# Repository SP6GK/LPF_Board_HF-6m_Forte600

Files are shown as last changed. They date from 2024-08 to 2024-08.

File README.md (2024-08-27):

# LPF_Board_HF-6m_Forte600
Design of a LPF board with 6 filters covering entire HF spectrum and 6 m band. Suitable for 600 W (or more) LDMOS/BJT amplifiers.

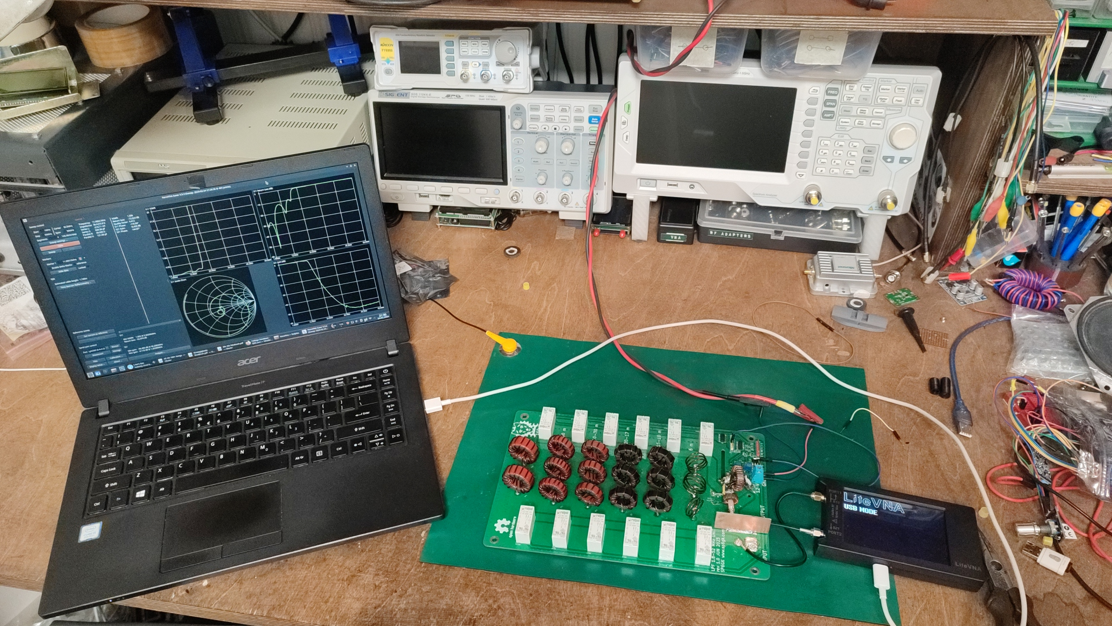
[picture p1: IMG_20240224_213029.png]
LPF_PCB


## Overview

For a detailed theory of operation and a description of the design process, you can read section 2.2.3 of my thesis: [Optimization of HF Amplifier TLT Forte600 Documentation](https://github.com/SP6GK/Forte-600-HF-RF-Amplifier/blob/main/Optimization_HF_amplifier_TLT_Forte600Documentation.pdf).

This low pass filter board was designed for a 600 W amplifier and successfully withstood 600 W of CW power with no issues. It is overrated to handle about 1 kW, however, in such case, the size of some of the toroids should be increased.  
These filters used in the Forte 600 ([Forte 600 project repo](https://github.com/SP6GK/Forte-600-HF-RF-Amplifier)) provide a worst-case harmonic suppression of 54 dBc for the 15 m band. Check the `/Results` directory for S21 and S11 measurements, or refer to sections 4.7 and 4.8 of my thesis for a more in-depth discussion of the results: [Optimization of HF Amplifier TLT Forte600 Documentation](https://github.com/SP6GK/Forte-600-HF-RF-Amplifier/blob/main/Optimization_HF_amplifier_TLT_Forte600Documentation.pdf).  
During assembly use only high quality, high current capable, COG capacitors rated at 1 kV or more.

The board includes a tandem match coupler, allowing the forward and reflected power at the output to be measured. The desired LPF is selected either by applying a low level 5 V signal to connector J4, which requires 7 wires, or by driving a shift register (U2) directly from a microcontroller (3.3 V to 5 V) using only 3 wires.  
The code for band changing and shift register driving is available in my repository for the LDMOS amplifier controller: [Link](https://github.com/SP6GK/RF_Power_Amplifier_Controller_V1).  
To find out more about the Forte 600 project, you can visit my website: [www.sp6gk.com](https://www.sp6gk.com/).

## Directory Structure

- **/bom**  
  Contains an interactive HTML BOM for assembly and the `BOM_LC.ods` spreadsheet, which indicates the number of turns and suggested values for capacitors, ensuring that the combined capacitance value is achieved using at least 4 parallel capacitors.

- **/Gerbers**  
  Files for sending the project to your favorite PCB fabricator.

- **/KiCad**  
  Contains the PCB project files.

- **/PDF**  
  Contains 1:1 scale prints of the copper and silk screen layers.

- **/Results**  
  Contains S21 and S11 measurements of the assembled board. Measurements were made using a calibrated LiteVNA 64, and .s2p files were plotted in AWR Designer.

- **Coilformer1y.stl** & **Coilformer2.stl**  
  Temporary coil formers for the 6m band, which you can 3D print and then wind the coil on.

- **LPF.asc**  
  LTspice simulation of the LPF filters.

- **LPF+6m_Schematic.pdf**  
  schematic document.

- **LPF_live.mlx**  
  A MATLAB Live Script for the calculation of LC elements, formulas and values for polynomials were sourced from "Experimental Methods in RF Design" book.

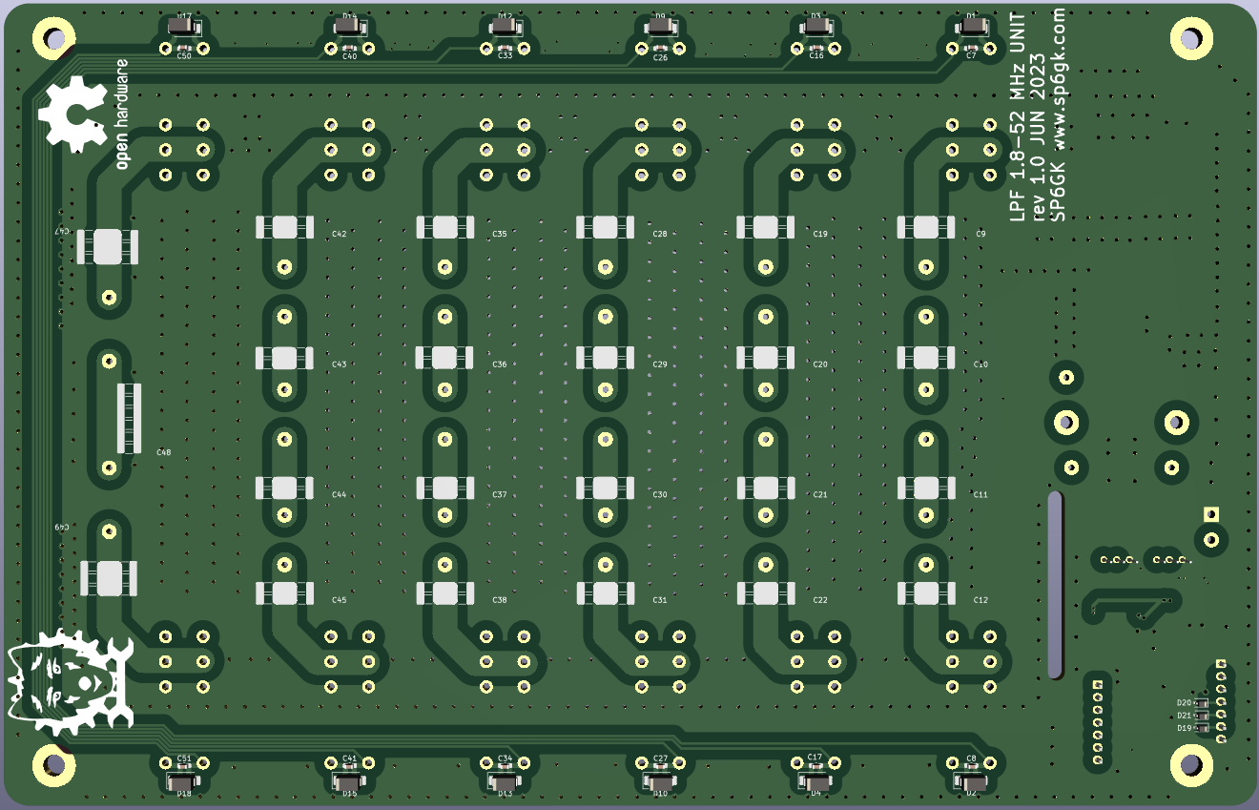
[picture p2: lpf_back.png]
LPF_back


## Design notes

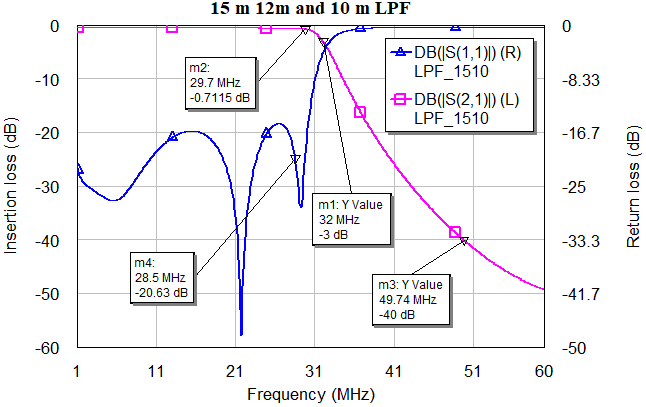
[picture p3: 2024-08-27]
AWR_1510m2.png

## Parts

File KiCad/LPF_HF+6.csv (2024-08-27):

null | Sourced | Placed | References | Value | Footprint | Quantity
1 |  |  | C1, C2, C3, C4, C5, C6, C8, C9, C10, C11, C12, C13, C14, C16, C18, C20, C39, C44, C45, C47, C50 | 100n | 0603 | 21
2 |  |  | C25, C31, C37, C43 | 834p | 4x1206_2 | 4
3 |  |  | C19, C46, C49 | 1u | 0603 | 3
4 |  |  | C26, C32, C38 | C_Small | 6x1206 | 3
5 |  |  | C7, C17 | 10u | 1206 | 2
6 |  |  | C21, C39 | 71p | 4x1206_2 | 2
7 |  |  | C22, C40 | 123p | 4x1206_2 | 2
8 |  |  | C23, C41 | 203p | 4x1206_2 | 2
9 |  |  | C24, C42 | 357p | 4x1206_2 | 2
10 |  |  | C27, C33 | 127p | 4x1206_2 | 2
11 |  |  | C28, C34 | 218p | 4x1206_2 | 2
12 |  |  | C29, C35 | 360p | 4x1206_2 | 2
13 |  |  | C30, C36 | 635p | 4x1206_2 | 2
14 |  |  | C48, C51 | 10n | 0603 | 2
15 |  |  | C15 | 10u | 1206 | 1
16 |  |  | R2, R3, R4, R5, R12, R13 | 100 | 0603 | 6
17 |  |  | R6, R7, R9, R10 | 100 | 2010 | 4
18 |  |  | R8, R11 | 10k | 0603 | 2
19 |  |  | R1 | 10 | 0603 | 1
20 |  |  | L1, L2, L3, L4, L5, L7, L8, L9, L10, L11, L13, L14, L15, L16, L17 | L | T94-Inductor | 15
21 |  |  | L6, L12 | L | T106-Inductor | 2
22 |  |  | L20, L21 | 100u | 0805 | 2
23 |  |  | L18 | FT50-61 30T 1T RG-142 coax | T94-SWR_TRAFO | 1
24 |  |  | L19 | FT82-61 30T 1T-RG213 coax | T94-SWR_TRAFO | 1
25 |  |  | D1, D2, D3, D4, D5, D6, D10, D11, D12, D13, D14, D15 | 1N4007 | D_SMA | 12
26 |  |  | D7, D8, D9, D16, D17, D18, D21, D22 | SD12_SOD323 | D_SOD-323 | 8
27 |  |  | D19, D20 | Schottky | D_SMA | 2
28 |  |  | U1 | AMS1117-5 | SOT-223-3_TabPin2 | 1
29 |  |  | U2 | 74AHC595 | SO-16_3.9x9.9mm_P1.27mm | 1
30 |  |  | U3 | ULN2003 | SO-16_3.9x9.9mm_P1.27mm | 1
31 |  |  | REL1, REL2, REL3, REL4, REL5, REL6, REL7, REL8, REL9, REL10, REL11, REL12 | RM85 | RM85_Relay | 12
32 |  |  | RV1, RV2 | 10k | Potentiometer_Bourns_3266Y_Vertical | 2
33 |  |  | J1, J4 | Conn_01x07 | JST_EH_B7B-EH-A_1x07_P2.50mm_Vertical | 2
34 |  |  | J2 | 12V INPUT | TerminalBlock_bornier-2_P5.08mm | 1
35 |  |  | J3 | RF input | Coax_Mount | 1
36 |  |  | J5 | RF output | Coax_Mount | 1

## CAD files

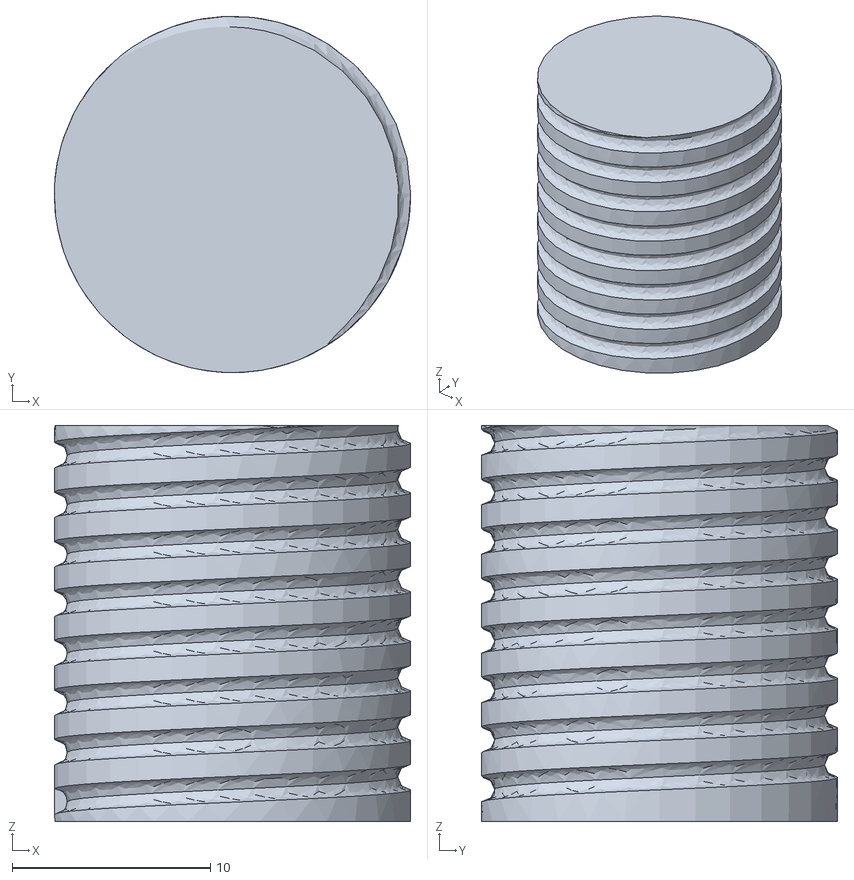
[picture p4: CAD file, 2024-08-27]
Coilformer1y.stl
18.0 x 18.0 x 20.0

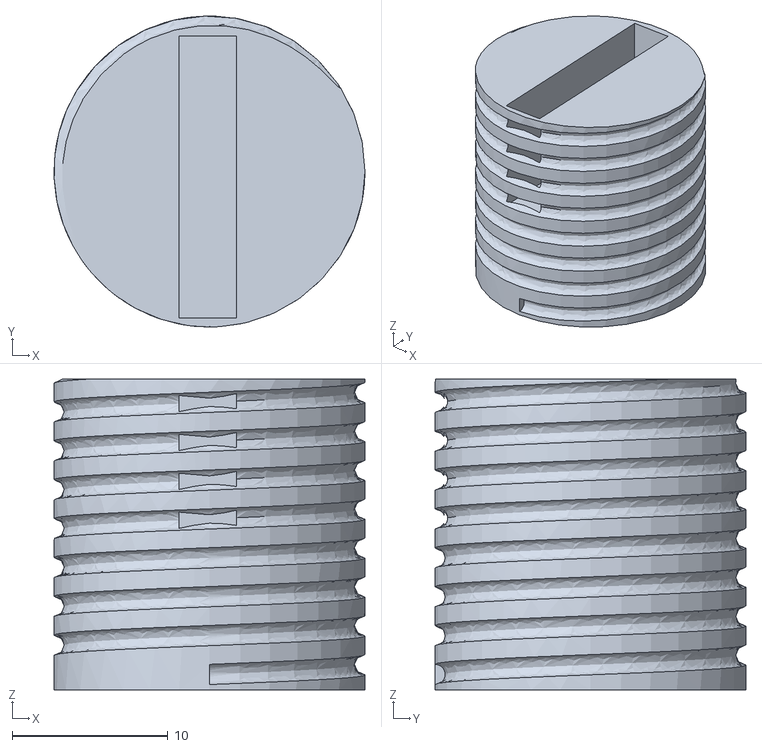
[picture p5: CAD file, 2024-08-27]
Coilformer2.stl
20.0 x 20.0 x 20.0

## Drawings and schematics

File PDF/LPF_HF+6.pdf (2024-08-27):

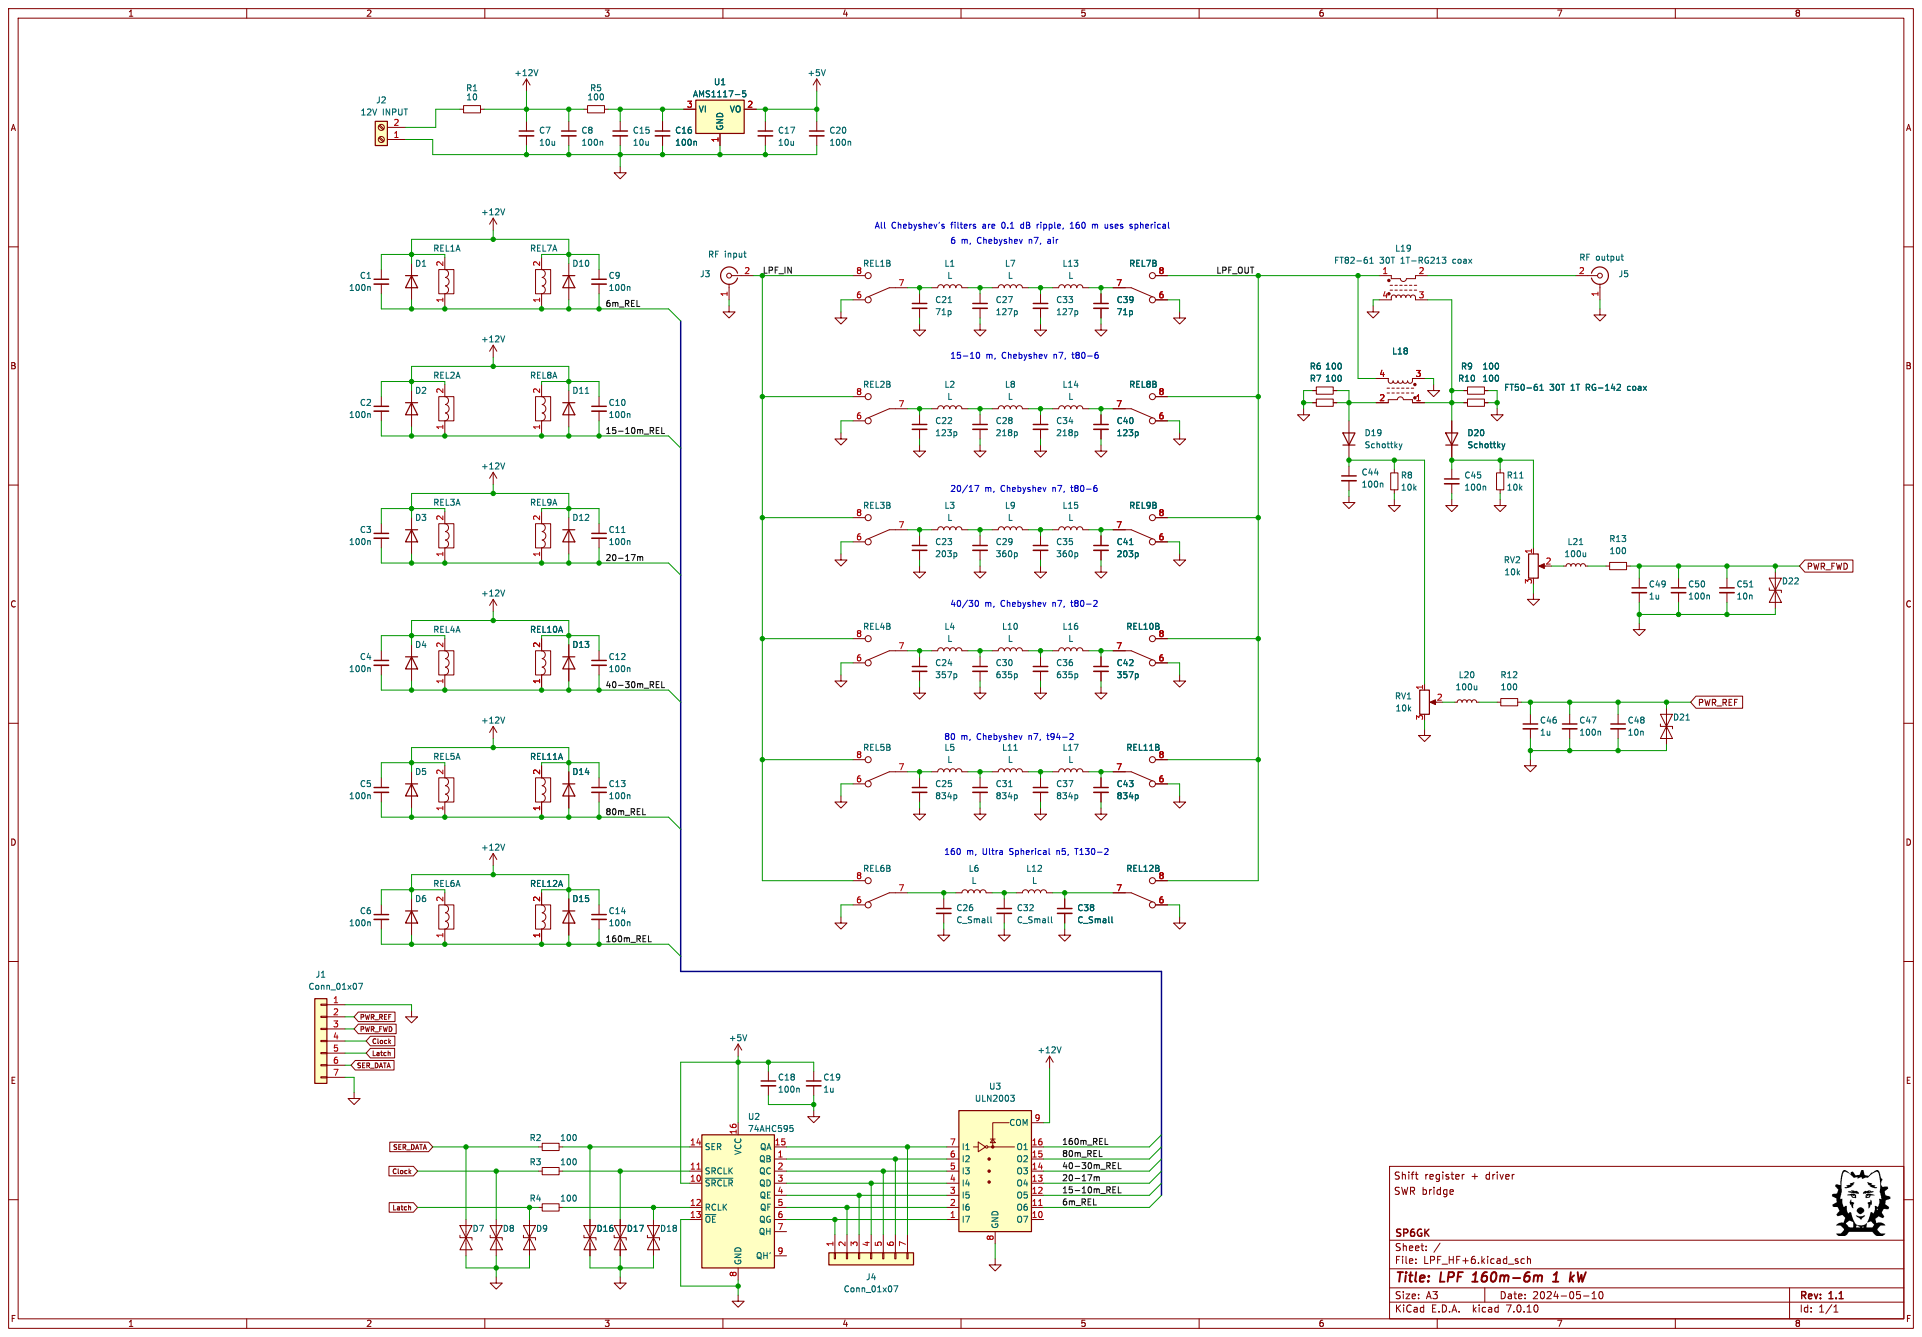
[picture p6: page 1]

1 2 REL12A R2 100 R3 100 D18 QB 1 ~{SRCLR} 10 SRCLK 11 RCLK 12 ~{OE} 13 SER 14 QA 15 VCC 16 QC 2 QD 3 QE 4 QF 5 QG 6 QH 7 GND

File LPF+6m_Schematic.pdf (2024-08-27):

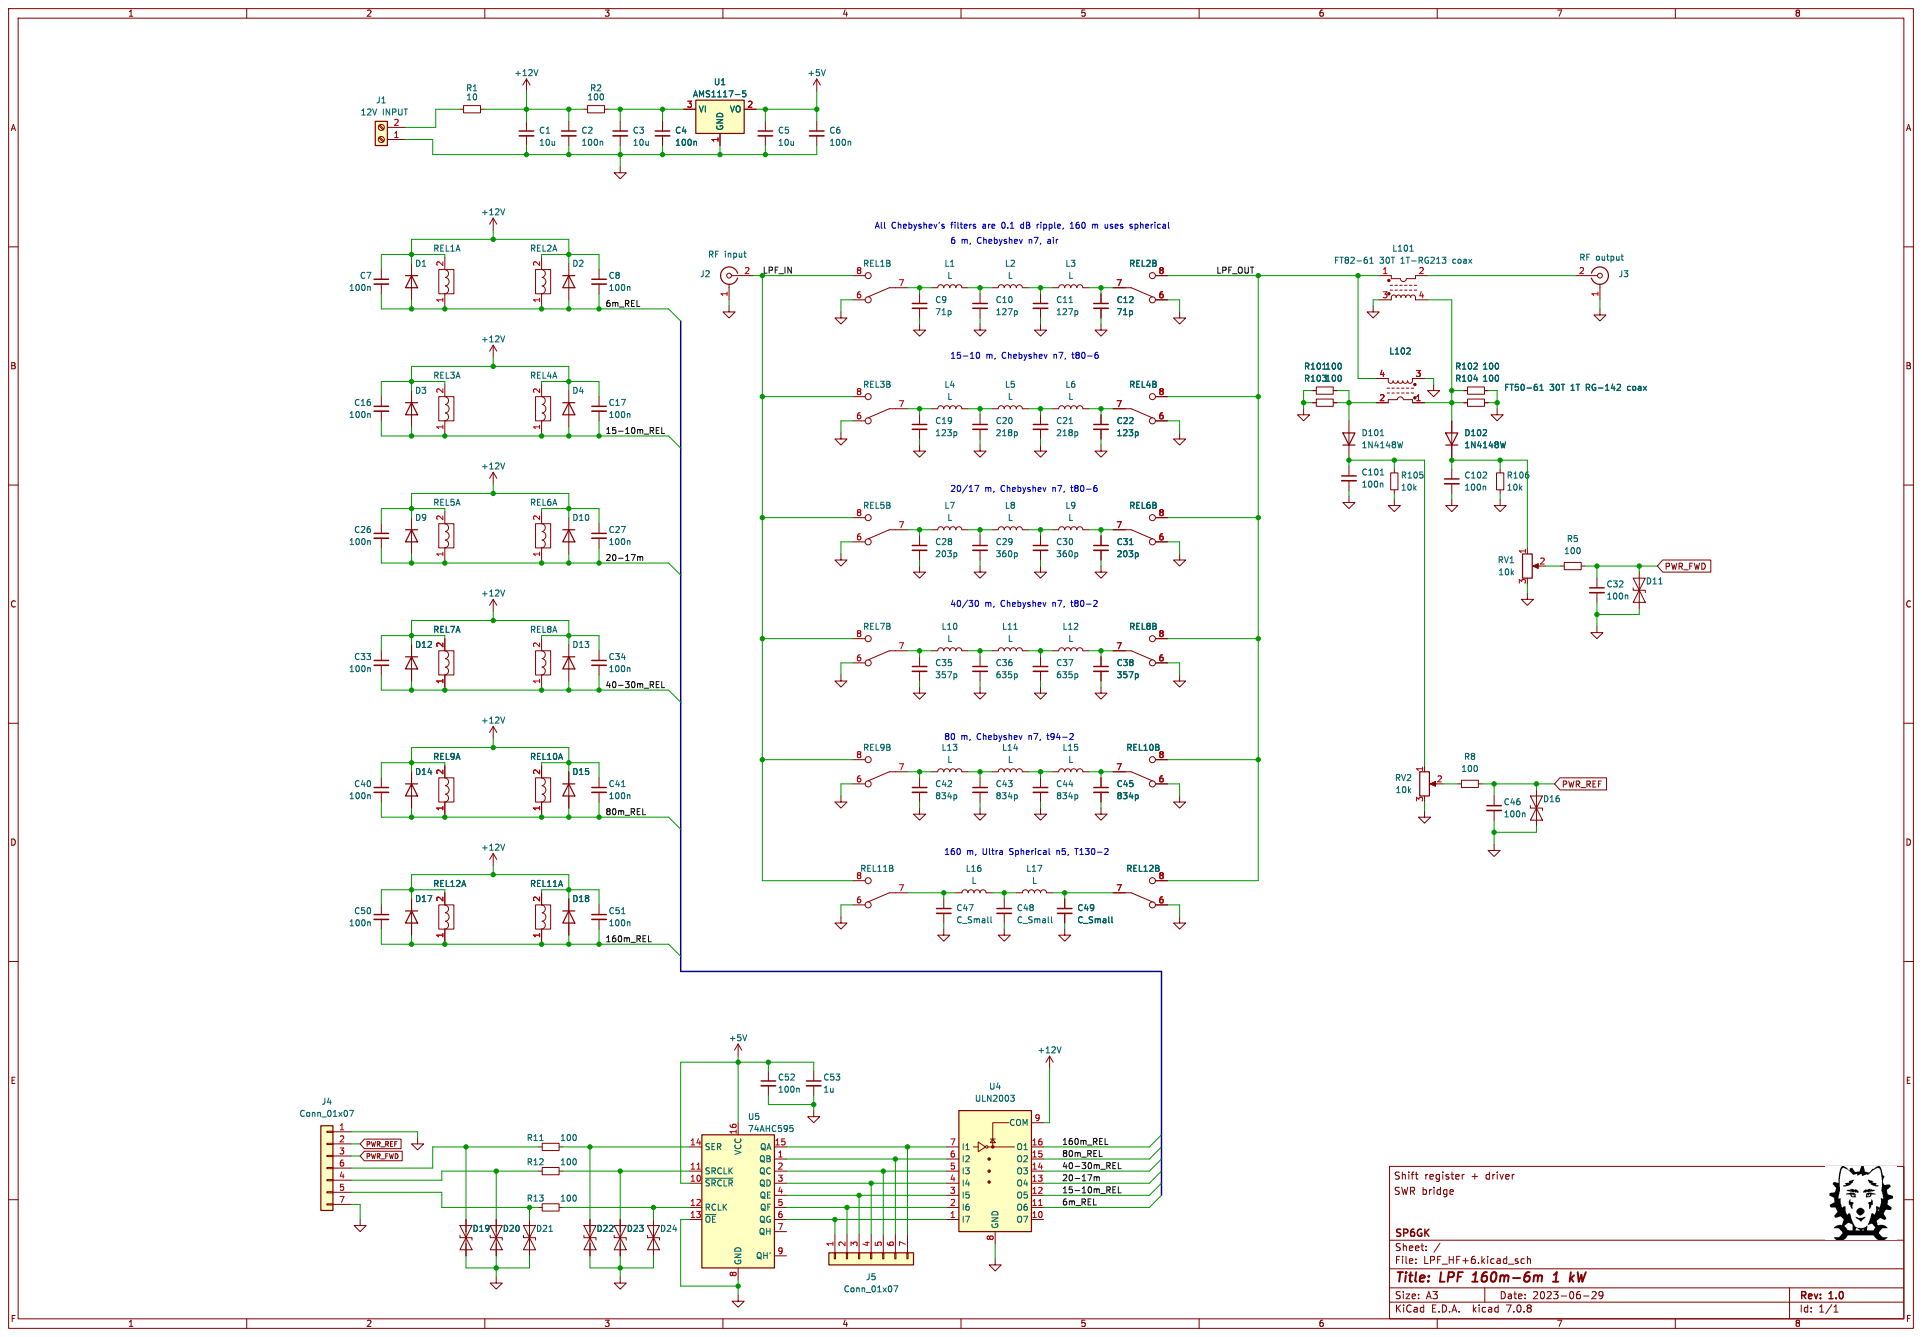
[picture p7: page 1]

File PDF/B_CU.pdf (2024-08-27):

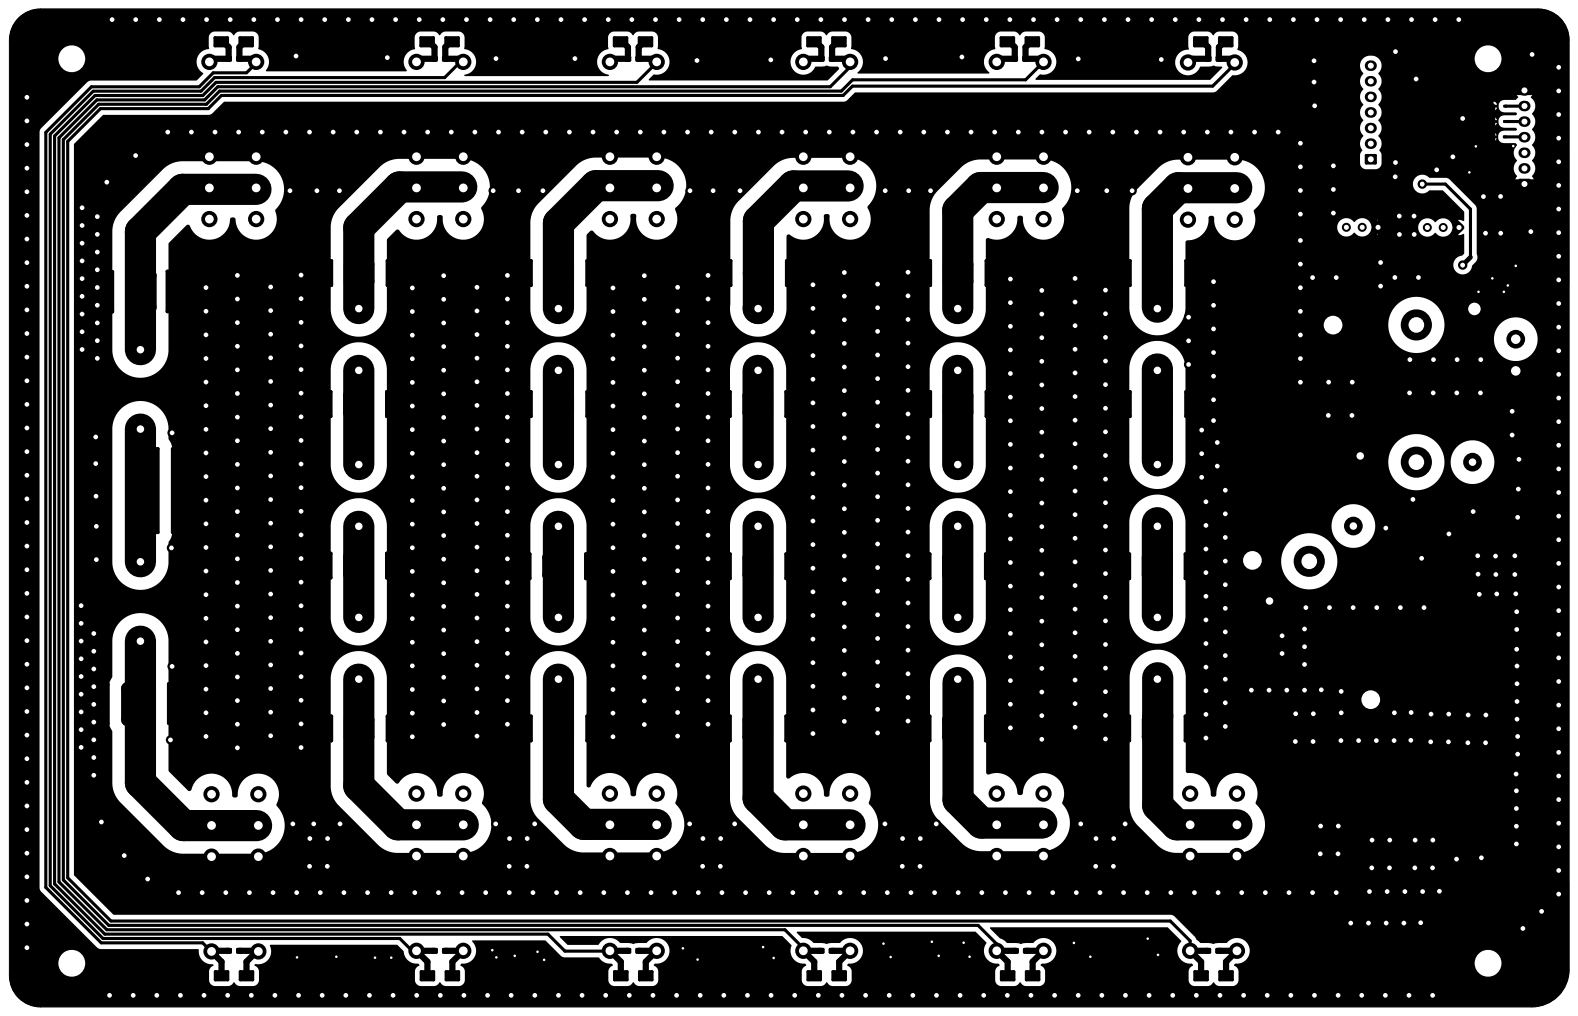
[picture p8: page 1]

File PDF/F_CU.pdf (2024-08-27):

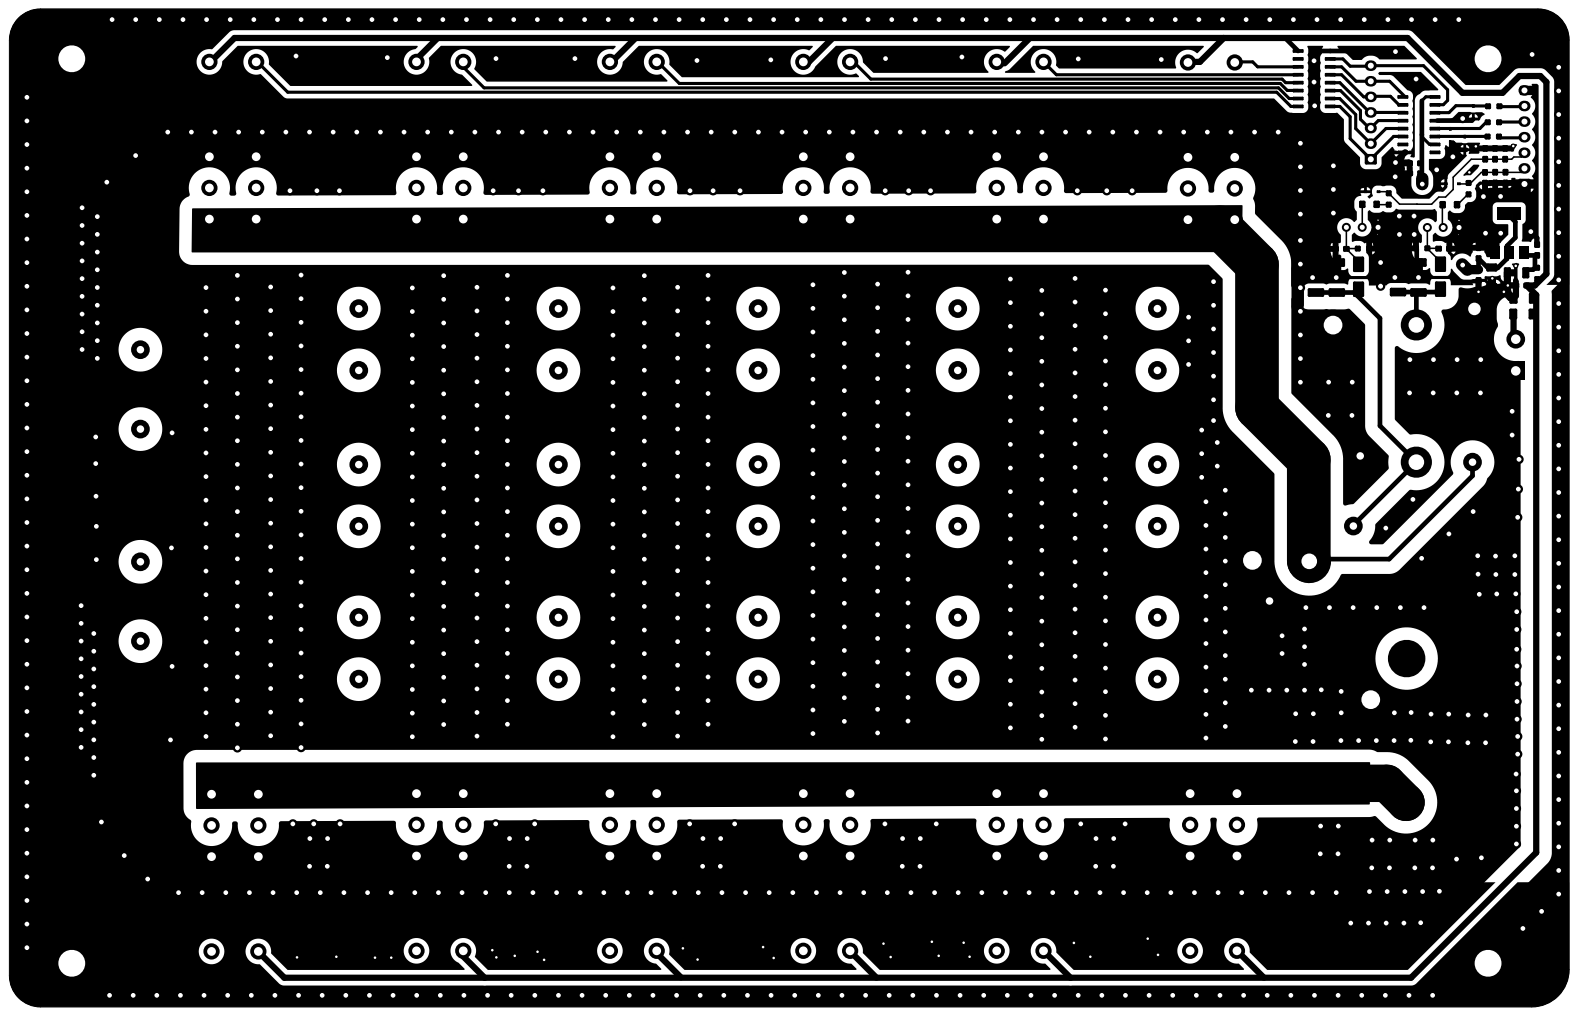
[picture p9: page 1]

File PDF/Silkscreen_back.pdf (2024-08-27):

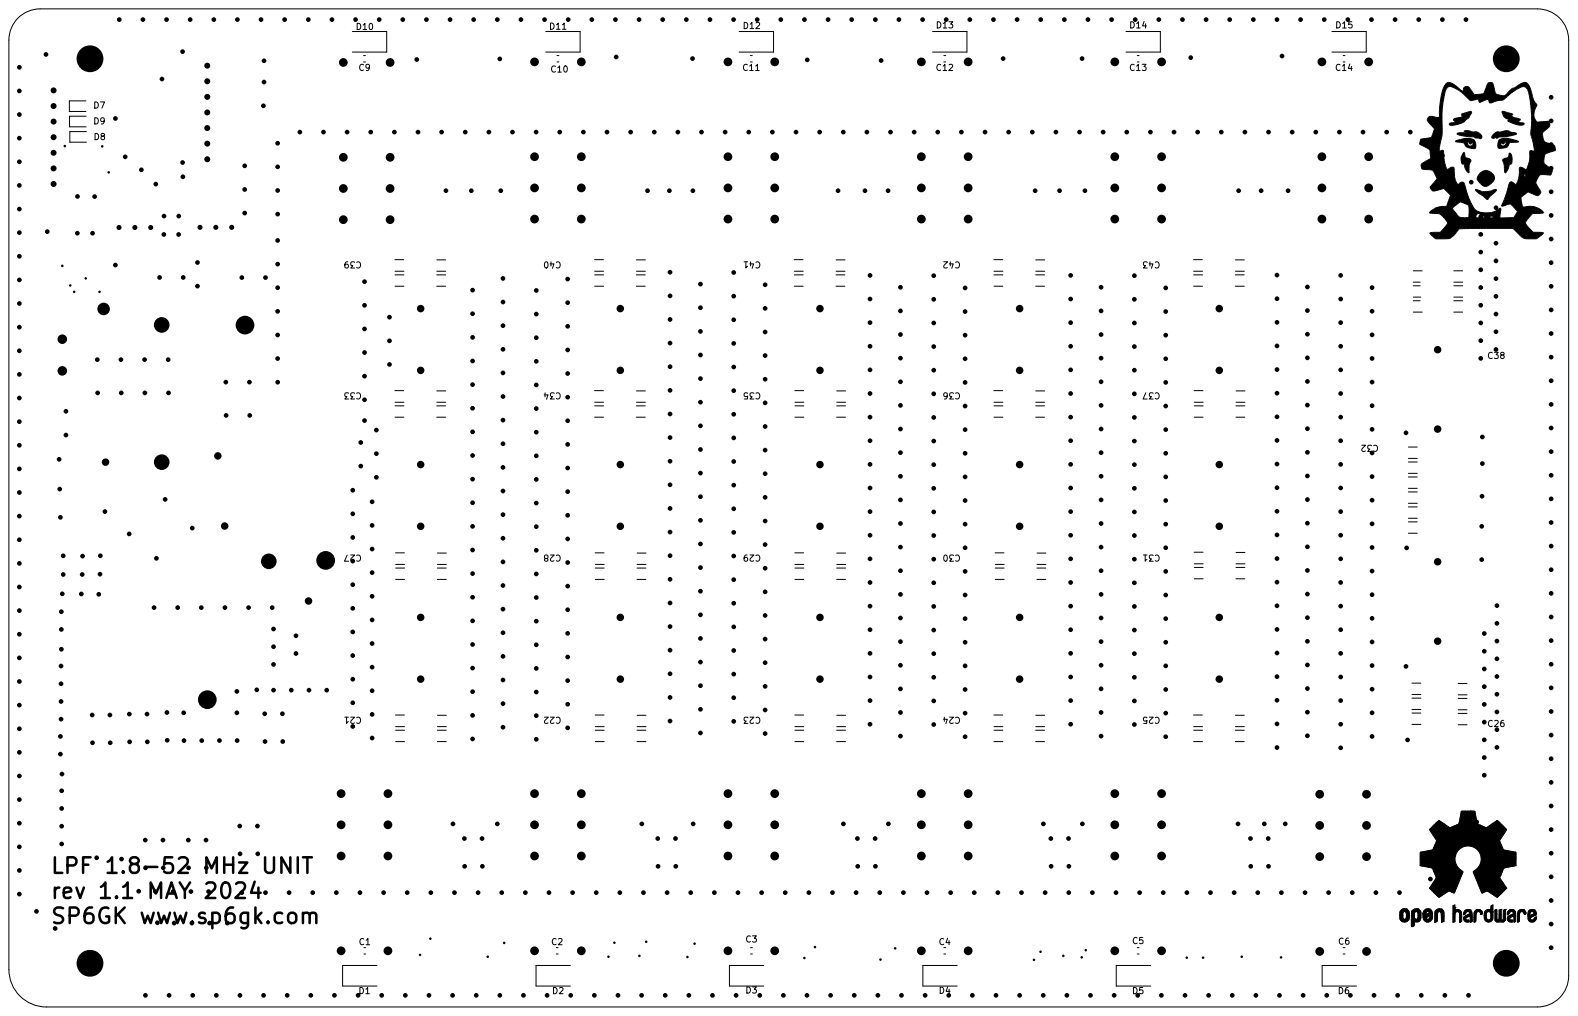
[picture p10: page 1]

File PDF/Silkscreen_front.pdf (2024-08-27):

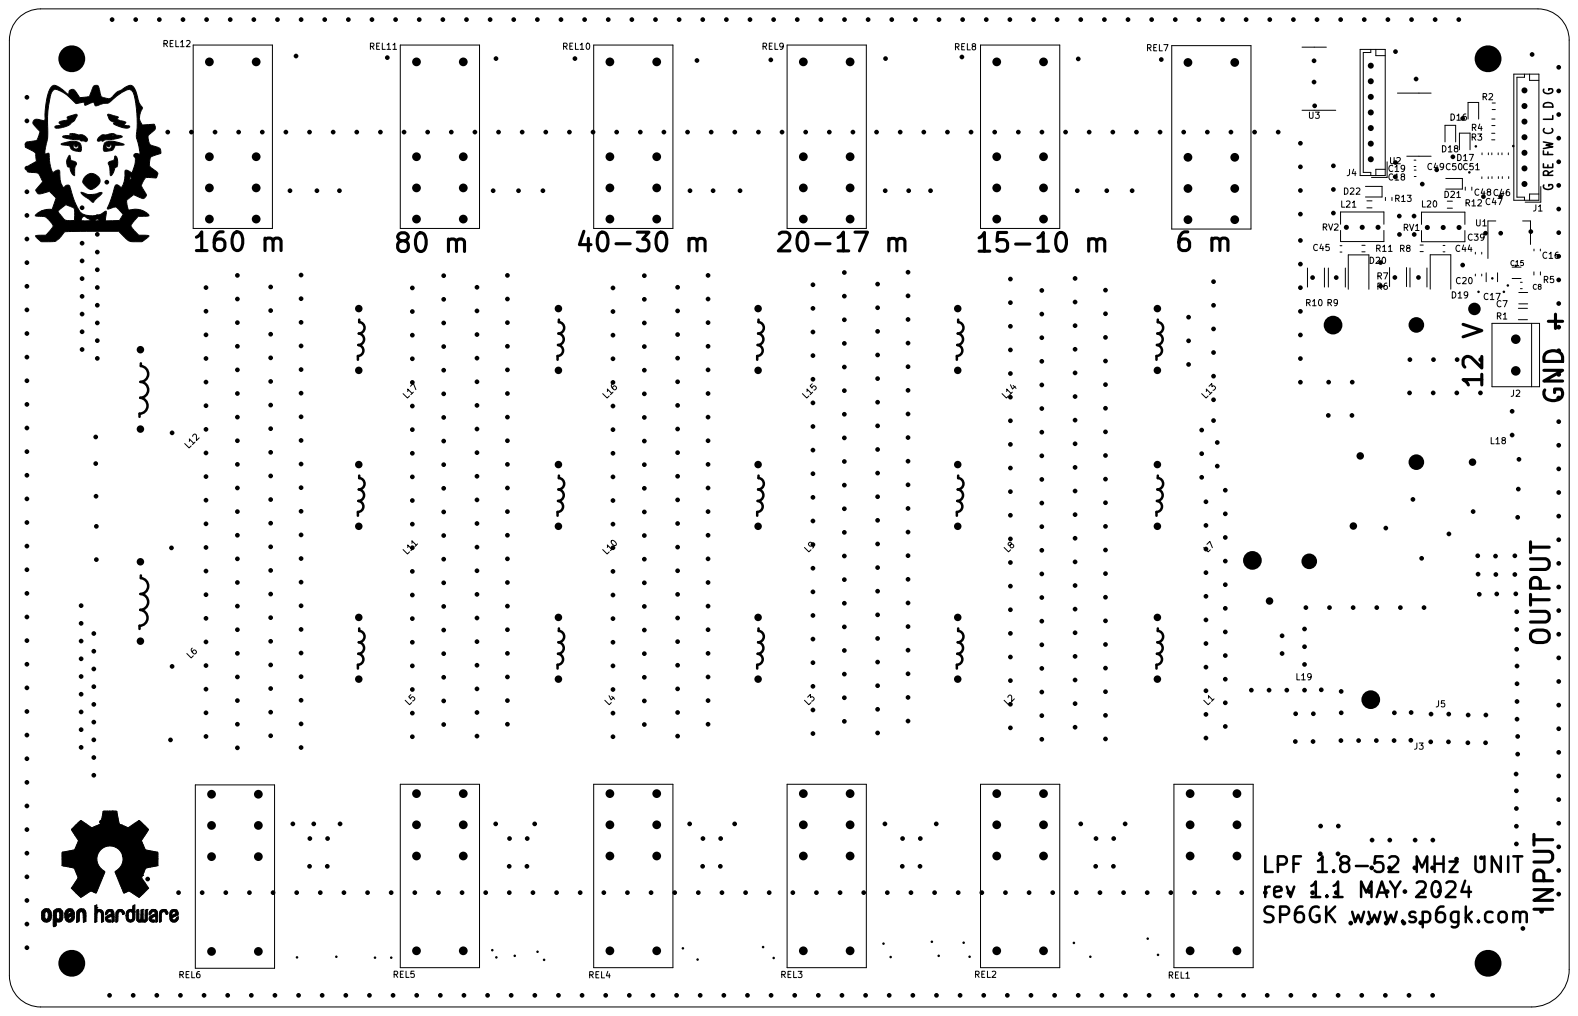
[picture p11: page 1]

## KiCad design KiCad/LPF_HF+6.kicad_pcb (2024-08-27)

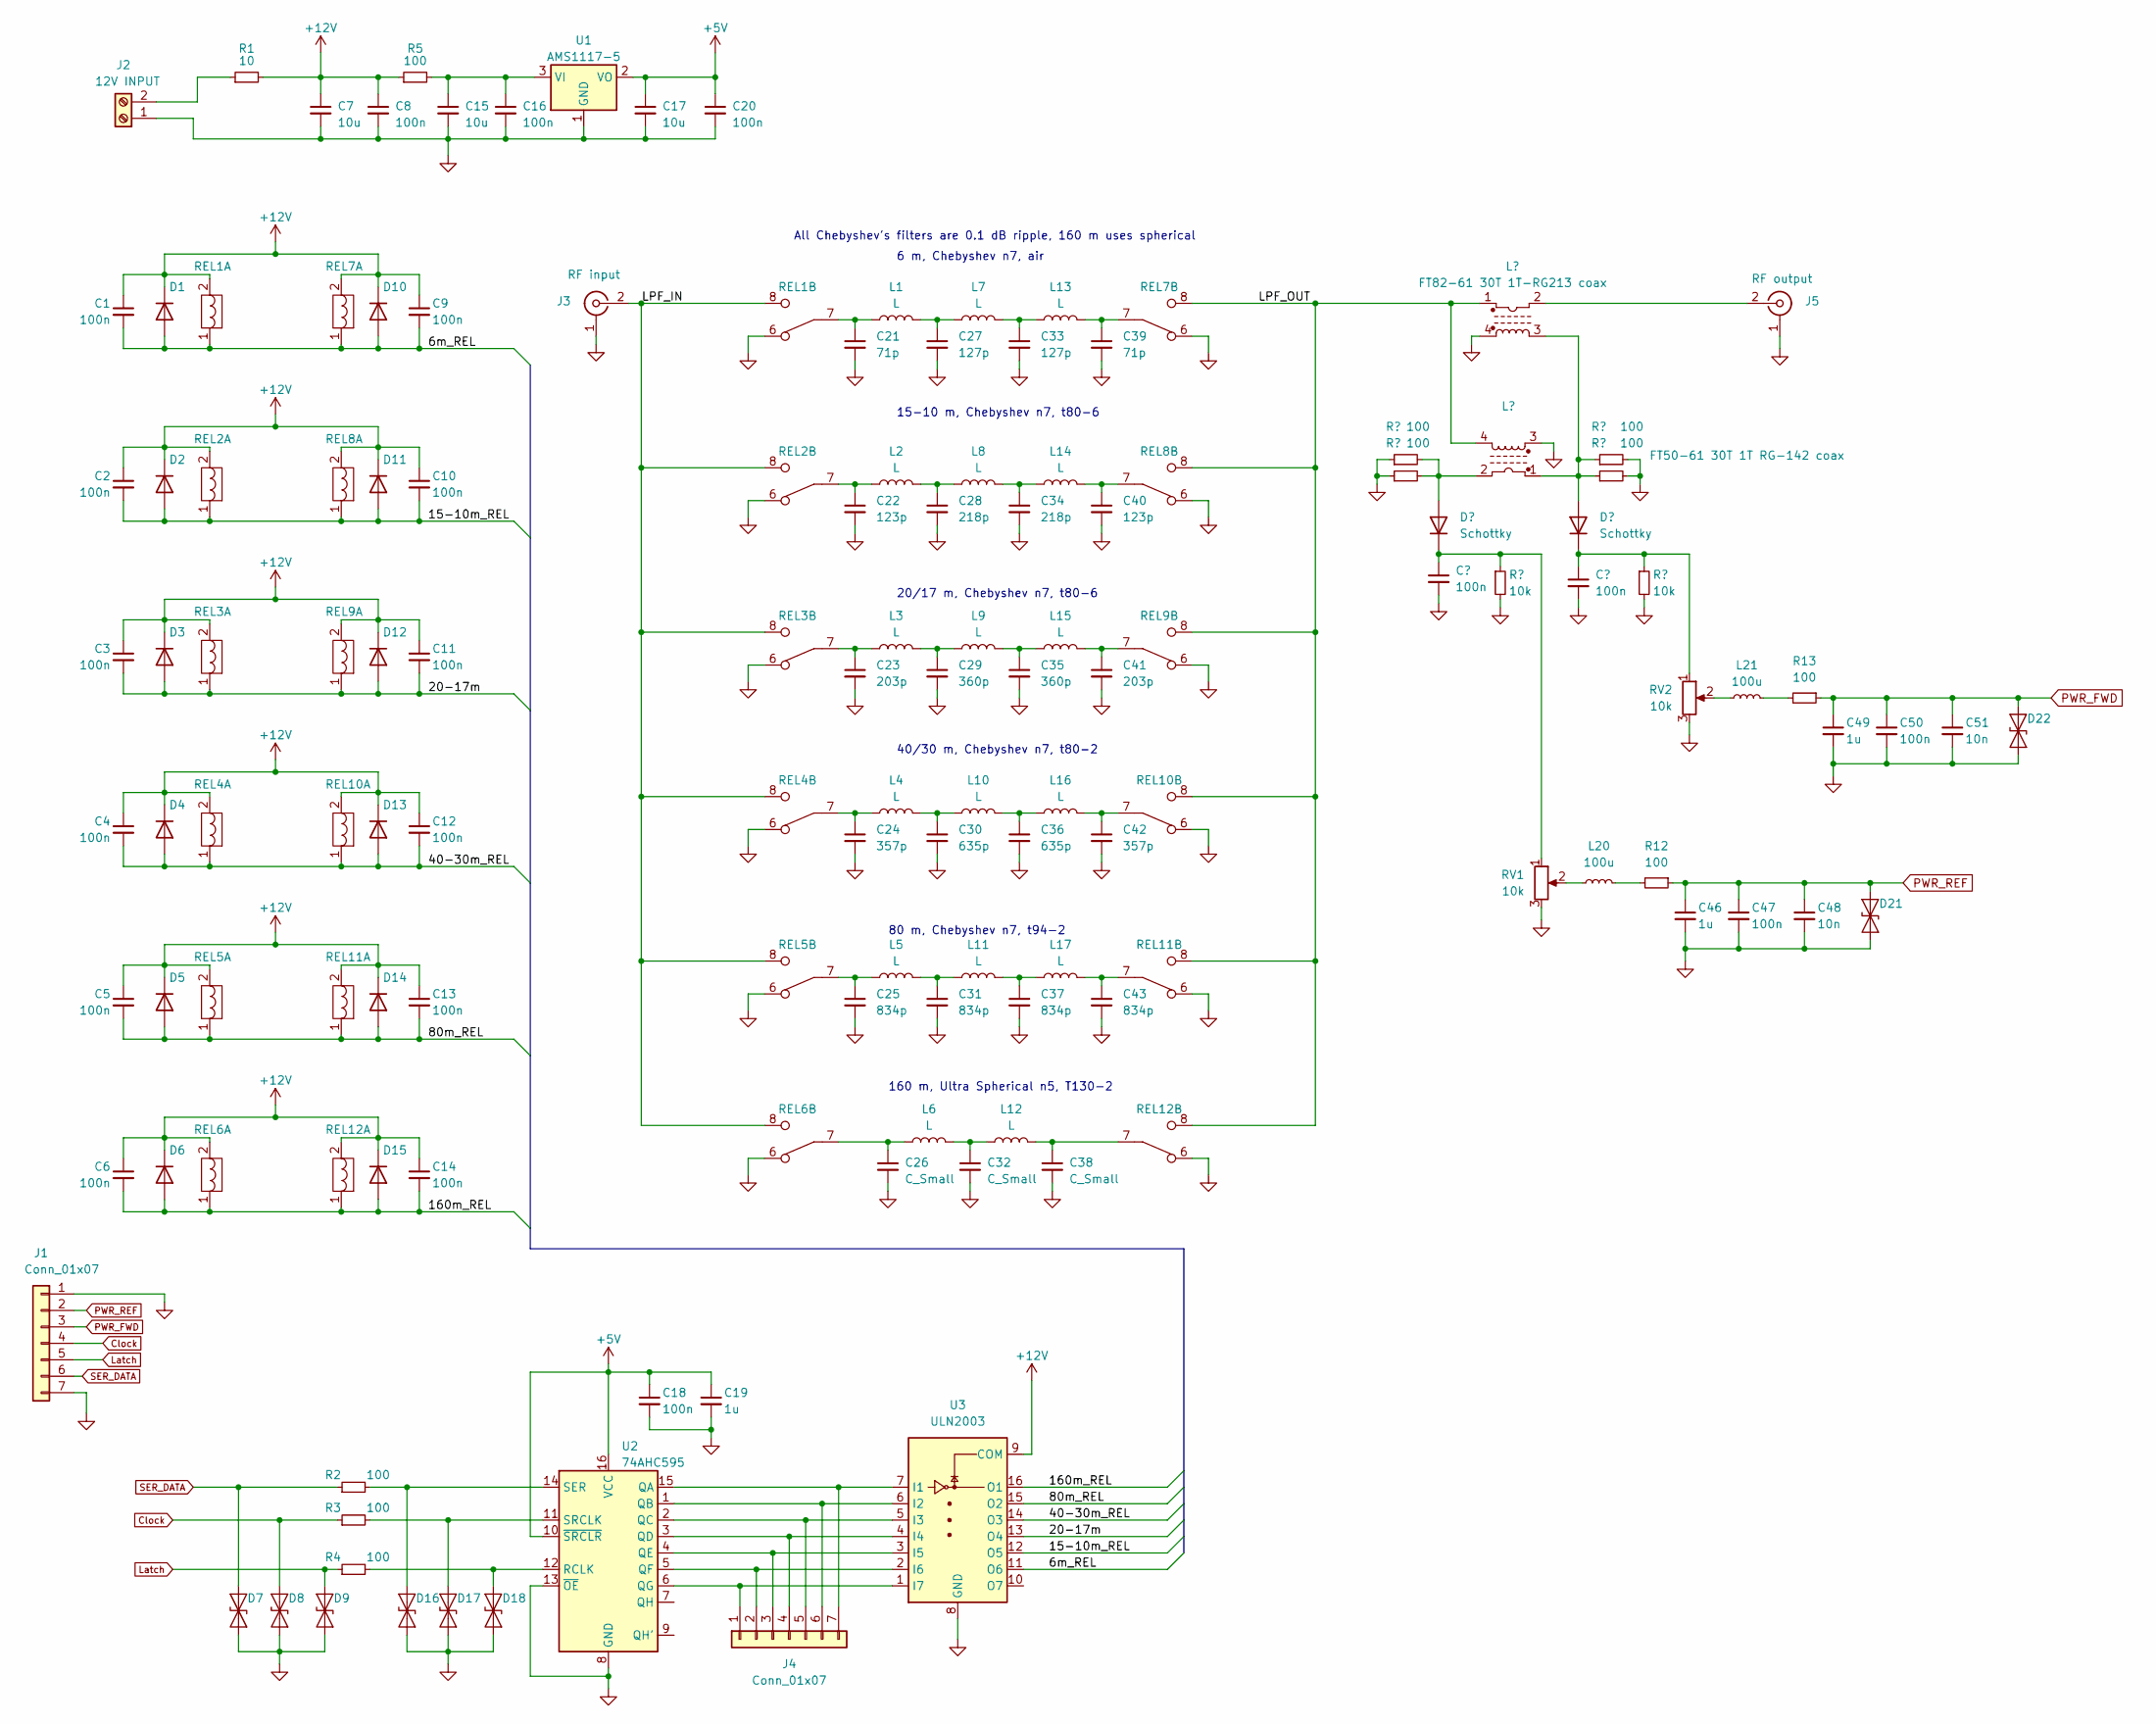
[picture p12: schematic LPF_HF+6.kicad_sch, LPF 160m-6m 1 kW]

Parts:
C1, C2, C3, C4, C5, C6, C8, C9, C10, C11, C12, C13, C14, C16, C18, C20, C44, C45, C47, C50: 100n; C_0603_1608Metric_Pad1.08x0.95mm_HandSolder
C7, C17: 10u; C_1206_3216Metric_Pad1.33x1.80mm_HandSolder
C15: 10u; C_1206_3216Metric
C19, C46, C49: 1u; C_0603_1608Metric_Pad1.08x0.95mm_HandSolder
C21, C39: 71p; 4x1206_2
C22, C40: 123p; 4x1206_2
C23, C41: 203p; 4x1206_2
C24, C42: 357p; 4x1206_2
C25, C31, C37, C43: 834p; 4x1206_2
C26, C32, C38: C_Small; 6x1206
C27, C33: 127p; 4x1206_2
C28, C34: 218p; 4x1206_2
C29, C35: 360p; 4x1206_2
C30, C36: 635p; 4x1206_2
C48, C51: 10n; C_0603_1608Metric_Pad1.08x0.95mm_HandSolder
D1, D2, D3, D4, D5, D6, D10, D11, D12, D13, D14, D15: 1N4007; D_SMA
D7, D8, D9, D16, D17, D18, D21, D22: SD12_SOD323; D_SOD-323
D19, D20: Schottky; D_SMA
J1, J4: Conn_01x07; JST_EH_B7B-EH-A_1x07_P2.50mm_Vertical
J2: 12V INPUT; TerminalBlock_bornier-2_P5.08mm
J3: RF input; Coax_Mount
J5: RF output; Coax_Mount
L1, L2, L3, L4, L5, L7, L8, L9, L10, L11, L13, L14, L15, L16, L17: L; T94-Inductor
L6, L12: L; T106-Inductor
L18: FT50-61 30T 1T RG-142 coax; T94-SWR_TRAFO
L19: FT82-61 30T 1T-RG213 coax; T94-SWR_TRAFO
L20, L21: 100u; L_0805_2012Metric_Pad1.05x1.20mm_HandSolder
R1: 10; R_1206_3216Metric_Pad1.30x1.75mm_HandSolder
R2, R3, R4, R5, R12, R13: 100; R_0603_1608Metric_Pad0.98x0.95mm_HandSolder
R6, R7, R9, R10: 100; R_2010_5025Metric_Pad1.40x2.65mm_HandSolder
R8, R11: 10k; R_0603_1608Metric_Pad0.98x0.95mm_HandSolder
REL1, REL2, REL3, REL4, REL5, REL6, REL7, REL8, REL9, REL10, REL11, REL12: RM85; RM85_Relay
RV1, RV2: 10k; Potentiometer_Bourns_3266Y_Vertical
U1: AMS1117-5; SOT-223-3_TabPin2
U2: 74AHC595; SO-16_3.9x9.9mm_P1.27mm
U3: ULN2003; SO-16_3.9x9.9mm_P1.27mm

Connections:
+12V: C1.1, C2.1, C3.1, C4.1, C5.1, C6.1, C7.1, C8.1, C9.1, C10.1, C11.1, C12.1, C13.1, C14.1, D1.1 (K), D2.1 (K), D3.1 (K), D4.1 (K), D5.1 (K), D6.1 (K), D10.1 (K), D11.1 (K), D12.1 (K), D13.1 (K), D14.1 (K), D15.1 (K), R1.2, R5.1, REL1.2, REL2.2, REL3.2, REL4.2, REL5.2, REL6.2, REL7.2, REL8.2, REL9.2, REL10.2, REL11.2, REL12.2, U3.9 (COM)
/6m_REL: C1.2, C9.2, D1.2 (A), D10.2 (A), REL1.1, REL7.1, U3.11 (O6)
/15-10m_REL: C2.2, C10.2, D2.2 (A), D11.2 (A), REL2.1, REL8.1, U3.12 (O5)
/20-17m: C3.2, C11.2, D3.2 (A), D12.2 (A), REL3.1, REL9.1, U3.13 (O4)
/40-30m_REL: C4.2, C12.2, D4.2 (A), D13.2 (A), REL4.1, REL10.1, U3.14 (O3)
/80m_REL: C5.2, C13.2, D5.2 (A), D14.2 (A), REL5.1, REL11.1, U3.15 (O2)
/160m_REL: C6.2, C14.2, D6.2 (A), D15.2 (A), REL6.1, REL12.1, U3.16 (O1)
/LPF_IN: J3.2 (In), REL1.5, REL1.8, REL2.5, REL2.8, REL3.5, REL3.8, REL4.5, REL4.8, REL5.5, REL5.8, REL6.5, REL6.8
/LPF_OUT: L18.4, L19.1, REL7.5, REL7.8, REL8.5, REL8.8, REL9.5, REL9.8, REL10.5, REL10.8, REL11.5, REL11.8, REL12.5, REL12.8
Clock: D8.1 (A1), J1.4, R3.1
GND: C7.2, C8.2, C15.2, C16.2, C17.2, C18.2, C19.2, C20.2, C21.2, C22.2, C23.2, C24.2, C25.2, C26.2, C27.2, C28.2, C29.2, C30.2, C31.2, C32.2, C33.2, C34.2, C35.2, C36.2, C37.2, C38.2, C39.2, C40.2, C41.2, C42.2, C43.2, C44.2, C45.2, C46.2, C47.2, C48.2, C49.2, C50.2, C51.2, D7.2 (A2), D8.2 (A2), D9.2 (A2), D16.2 (A2), D17.2 (A2), D18.2 (A2), D21.2 (A2), D22.2 (A2), J1.1, J1.7, J2.1, J3.1 (Ext), J5.1 (Ext), L18.3, L19.4, R6.1, R7.1, R8.2, R9.2, R10.2, R11.2, REL1.3, REL1.6, REL2.3, REL2.6, REL3.3, REL3.6, REL4.3, REL4.6, REL5.3, REL5.6, REL6.3, REL6.6, REL7.3, REL7.6, REL8.3, REL8.6, REL9.3, REL9.6, REL10.3, REL10.6, REL11.3, REL11.6, REL12.3, REL12.6, RV1.3, RV2.3, U1.1 (GND), U2.8 (GND), U2.13 (~OE), U3.8 (GND); also elsewhere on the board
Latch: D9.1 (A1), J1.5, R4.1
unnamed: C21.1, L1.1, REL1.4, REL1.7
unnamed: C22.1, L2.1, REL2.4, REL2.7
unnamed: C23.1, L3.1, REL3.4, REL3.7
unnamed: C24.1, L4.1, REL4.4, REL4.7
unnamed: C25.1, L5.1, REL5.4, REL5.7
unnamed: C26.1, L6.1, REL6.4, REL6.7
unnamed: C27.1, L1.2, L7.1
unnamed: C28.1, L2.2, L8.1
unnamed: C29.1, L3.2, L9.1
unnamed: C30.1, L4.2, L10.1
unnamed: C31.1, L5.2, L11.1
unnamed: C32.1, L6.2, L12.1
unnamed: C33.1, L7.2, L13.1
unnamed: C34.1, L8.2, L14.1
unnamed: C35.1, L9.2, L15.1
unnamed: C36.1, L10.2, L16.1
unnamed: C37.1, L11.2, L17.1
unnamed: C38.1, L12.2, REL12.4, REL12.7
unnamed: C40.1, L14.2, REL8.4, REL8.7
unnamed: C41.1, L15.2, REL9.4, REL9.7
unnamed: C42.1, L16.2, REL10.4, REL10.7
unnamed: C43.1, L17.2, REL11.4, REL11.7
unnamed: D16.1 (A1), R2.2, U2.14 (SER)
unnamed: D17.1 (A1), R3.2, U2.11 (SRCLK)
unnamed: D18.1 (A1), R4.2, U2.12 (RCLK)
unnamed: D19.2 (A), L18.2, R6.2, R7.2
unnamed: C44.1, D19.1 (K), R8.1, RV1.1
unnamed: D20.2 (A), L18.1, L19.3, R9.1, R10.1
unnamed: C45.1, D20.1 (K), R11.1, RV2.1
unnamed: J2.2, R1.1
unnamed: J4.1, U2.6 (QG), U3.1 (I7)
unnamed: J4.2, U2.5 (QF), U3.2 (I6)
unnamed: J4.3, U2.4 (QE), U3.3 (I5)
unnamed: J4.4, U2.3 (QD), U3.4 (I4)
unnamed: J4.5, U2.2 (QC), U3.5 (I3)
unnamed: J4.6, U2.1 (QB), U3.6 (I2)
unnamed: J4.7, U2.15 (QA), U3.7 (I1)
unnamed: J5.2 (In), L19.2
unnamed: L20.1, RV1.2
unnamed: L20.2, R12.2
unnamed: L21.1, RV2.2
unnamed: L21.2, R13.2
unnamed: C15.1, C16.1, R5.2, U1.3 (VI)
PWR_FWD: C49.1, C50.1, C51.1, D22.1 (A1), J1.3, R13.1
PWR_REF: C46.1, C47.1, C48.1, D21.1 (A1), J1.2, R12.1
SER_DATA: D7.1 (A1), J1.6, R2.1

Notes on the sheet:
15-10 m, Chebyshev n7, t80-6
6 m, Chebyshev n7, air
All Chebyshev's filters are 0.1 dB ripple, 160 m uses spherical
20/17 m, Chebyshev n7, t80-6
80 m, Chebyshev n7, t94-2
40/30 m, Chebyshev n7, t80-2
160 m, Ultra Spherical n5, T130-2

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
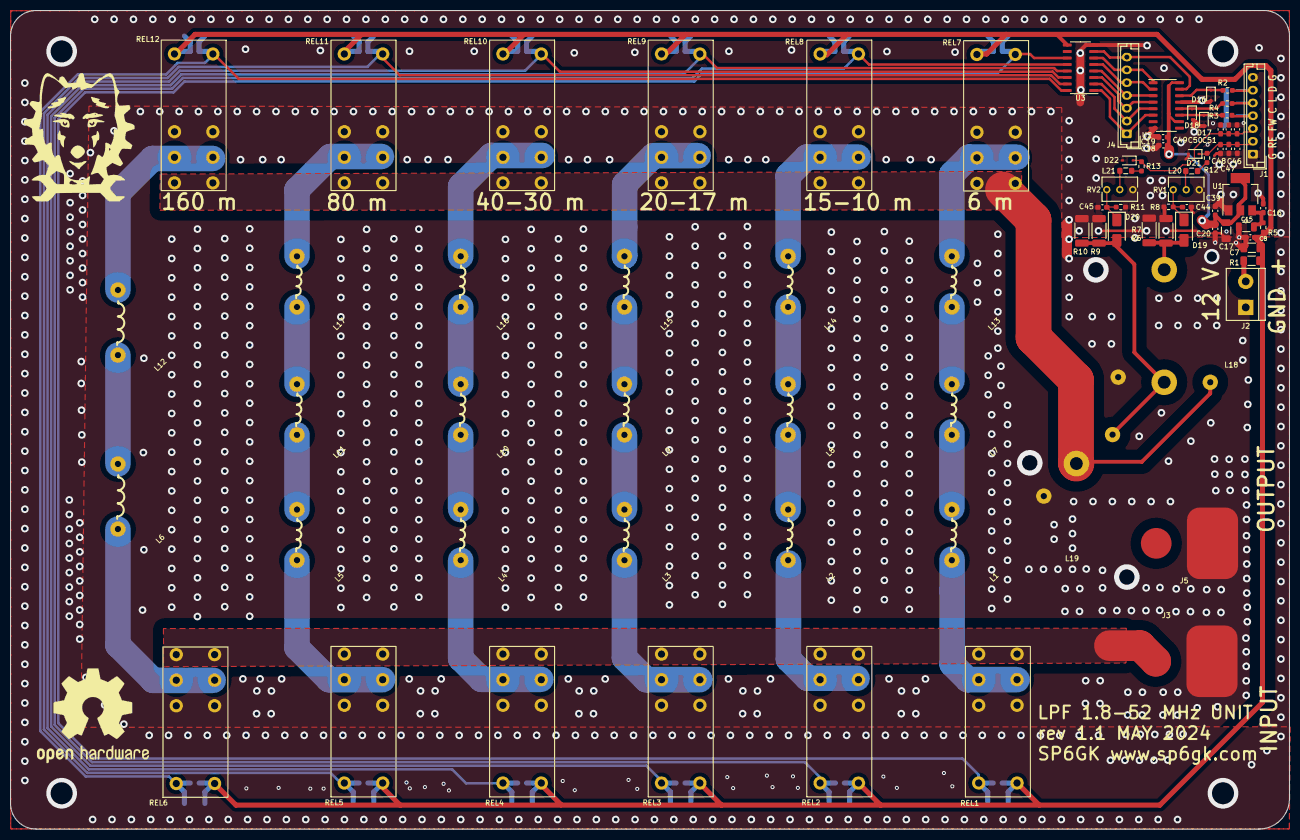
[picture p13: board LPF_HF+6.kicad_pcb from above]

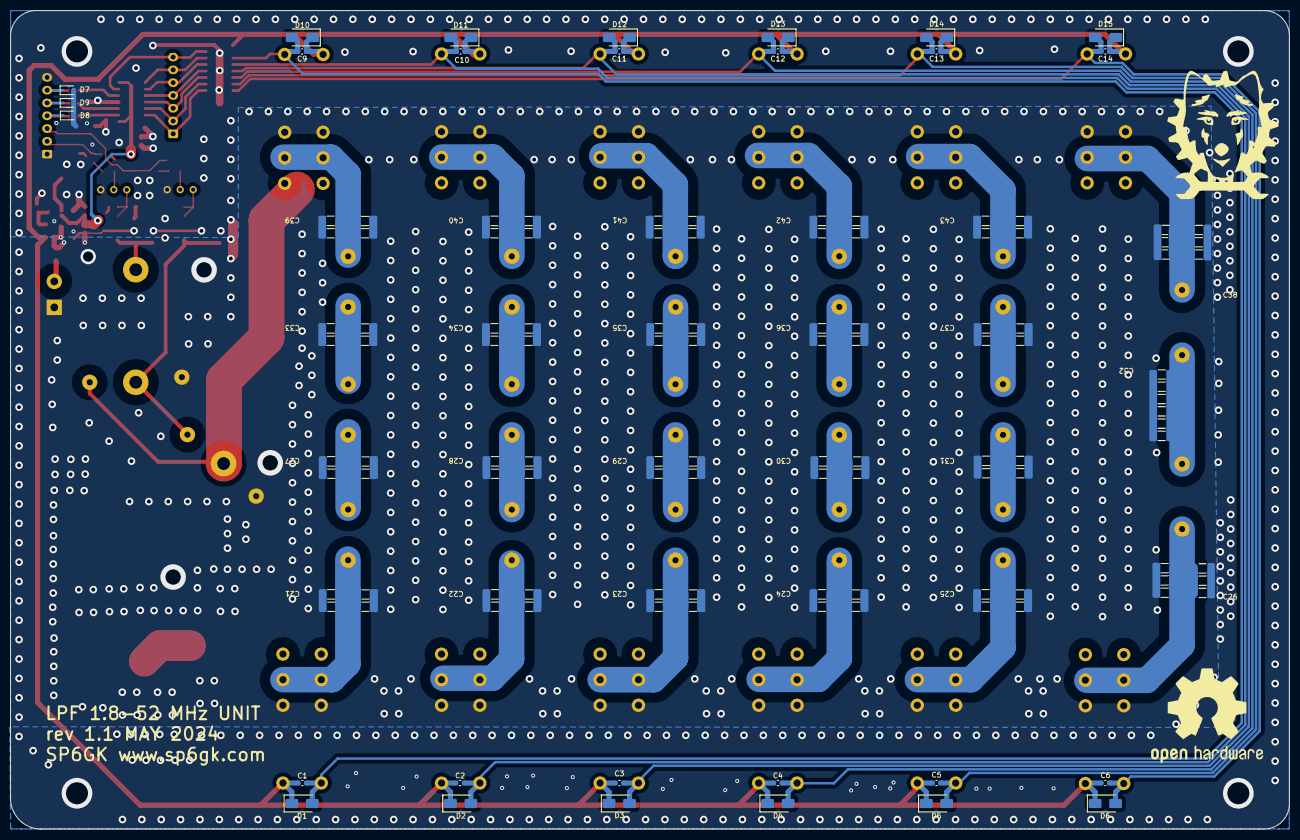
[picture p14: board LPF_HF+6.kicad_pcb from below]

Board: 2 copper layers, 250.0 x 160.0 mm, 130 parts (50 on the bottom side), 60 nets.

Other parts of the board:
C39#2: 71p; 4x1206_2

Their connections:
GND: C39#2.2; also elsewhere on the board
